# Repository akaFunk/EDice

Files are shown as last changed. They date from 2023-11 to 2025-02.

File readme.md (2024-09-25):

# EDice
The EDice is a small and fairly simple device that simulates a dice by using some LEDs, resistors and a microcontroller. The controller used is a Padauk PFS154-S16, which is an extremly cheap 8 bit microcontroller. It can be purchased from LCSC and other sources for less than 10 Euro-Cents.

The EDice is used as a simple soldering exercise. Therefore it has a combination of (relatively large) SMD and through-hole parts.

It is powered by a single CR2032 3V coin cell, which is on the back of the PCB. The holder we use is the BS-02-A1AJ010, which can also be purchased from LCSC for less than 5 Euro-Cents a pop.

Together with the PCB and a few other components, the whole cost is approximately 1€ in quantaties of about 100. This includes everything except the prommer (PCB, components, 3D case, shipping), which makes it ideal for a give-away item.

## Building
Building is pretty straight forward. A few things to note:
- Do not have a battery in the EDice while having it plugged into the prommer.
- The resistor values are quite flexible, depending on the LEDs you choose. However, the maximum source current of the microcontroller is 1.6mA on each pin. So a value of 1k or higher should be used. 1k is pretty bright though.

## BOM
We used LCSC for component sourcing. Here is our list:

- 100x microcontroller, PFS154-S16, C317613
- 100x battery holder, BS-02-A1AJ010, C5239862
- 100x button, K2-1102SP-J4SC-04, C879450
- 20x pin header,  12251140CNG0S115001,  C429959
- 700x 2.2k resistor, MFR0W8F2201A50, C58682
- 100x 100nF ceramic capacitor, CT4-0805Y104M500F1, C154503
- 700x red LED 5mm, XL-502SURD, C2895492
- 400x Screw M3x12, BB3X12, C357496

There are probably cheaper things out there, we did not look too hard into it.

## Programming

After installing the required software listed below, connect the EDice to the prommer (WITHOUT A BATTERY!) and run:

`make clean program run`

With the `run` command, the prommer will power the EDice and it should work right away.

### Programming in Linux
To program the Padauk microcontroller you need a Free-PDK prommer: https://free-pdk.github.io/

You also need to install the SDCC compiler (version 4.4.0 or higher) which you can install through your packet manager.

### Programming in Windows
Microsoft being Microsoft, it is a little more tricky to run make on Windows than it is on Linux. However, you san still do it - with a few extra steps. To run make and the programmer on Windows, you will need to:

- Install some kind of Linux shell for Windows like [Git Bash](https://gitforwindows.org/).
- Install some version of make for Windows. An easy way is using [Chocolatey](https://chocolatey.org/install) to install make by executing `choco install make` in an admin privileged command prompt.
- Install the [SDCC compiler](https://sourceforge.net/projects/sdcc/files/sdcc-win64/) (version 4.4.0 or higher). Make sure to use the provided setup.exe installer so the binary executable is added to your PATH automatically.
- Install the [Free-PDK prommer](https://github.com/free-pdk/easy-pdk-programmer-software/releases) by unpacking the .zip file, putting it somewhere with your other programs and adding the directory containing the file `easypdkprog` to your PATH manually.

After completing the installation, you can now compile and upload your code to the EDice by opening Git Bash (or another Linux Shell) in the directory containing the Makefile and running the commands listed in the section above.

## Using
Hold the button for a few seconds to roll the dice. A short press or waiting for ~20 seconds will put it in power-down mode, consuming less than 0.1µA. The battery should last for years.

## Cost
Hers is a short breakdown of the cost for 100 pcs:

- PCB at JLCPCB with shipping: 30€
- Components at LCSC with free/combined shipping (place PCB order first!): 34€
- CR2032 batteries from eBay/Amazon: 20€
- Material for 3D printing (1200g PLA): 25€

The total cost is then 99€ for 100 pcs.

This does not include the cost for the prommer, which are an additional ~25€.

## TODO
- Create a small adapter PCB for the prommer to fit into the EDice. A piece of breadboard and some pin headers will also do the trick.
- Update the 3D model and make new rendering

## License
The PCB and the images are licensed under CC-BY 4.0, the source code is under GPL v2.

For the PCB we used the KiCad symbols made by the free-pdk project: https://github.com/free-pdk/pdk-kicad-symbols/tree/master. This library is licensed under the CC-BY 4.0.

For the software the pdk-includes (GPL v2) https://github.com/free-pdk/pdk-includes and the easy-pdk-includes (GPL v2)  https://github.com/free-pdk/easy-pdk-includes are used.

## Images
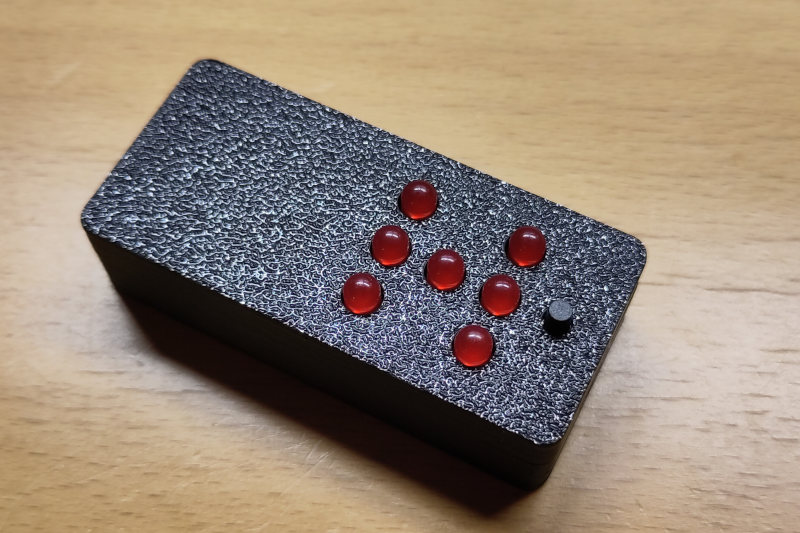
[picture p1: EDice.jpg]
EDice

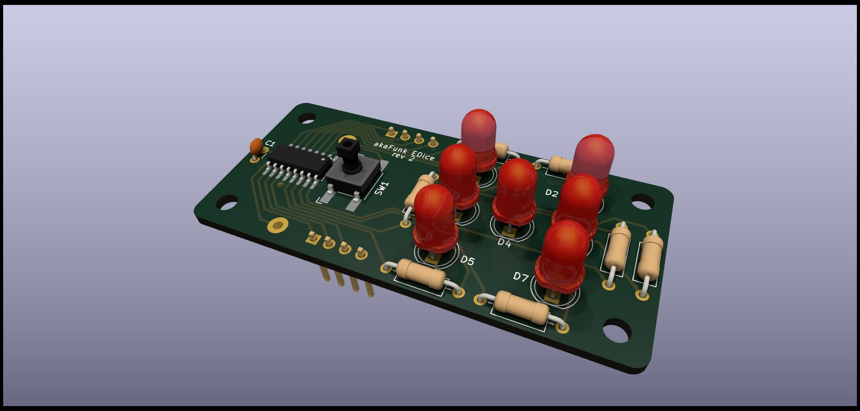
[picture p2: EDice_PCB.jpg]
EDice_PCB


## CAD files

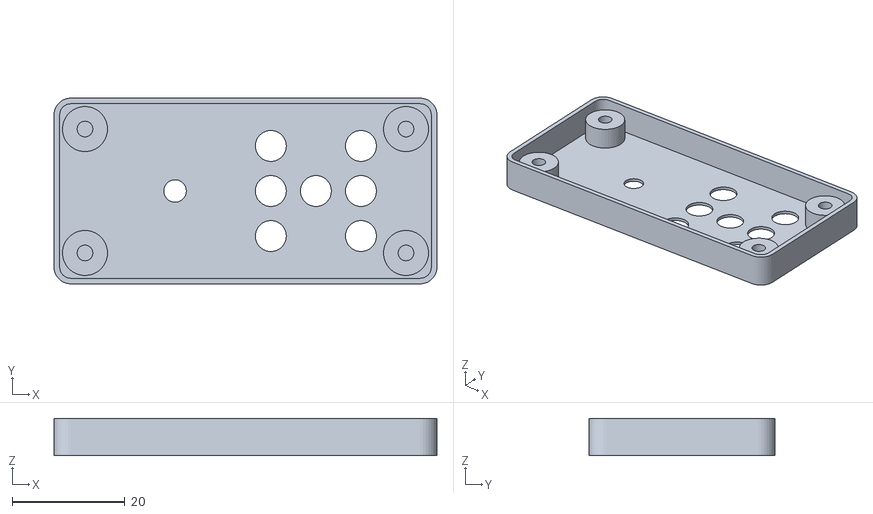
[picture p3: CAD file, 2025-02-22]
mechanical/EDiceTop.stl
68.0 x 33.0 x 6.60

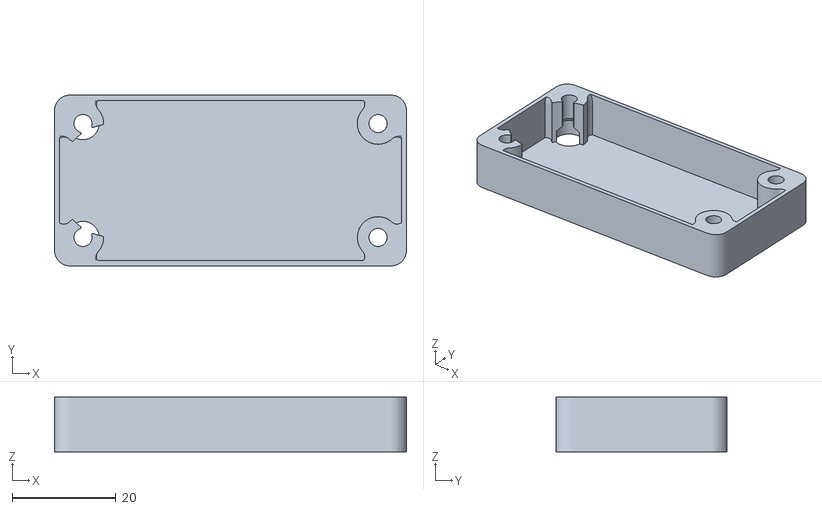
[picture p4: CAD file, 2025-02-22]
mechanical/EDiceBottom.stl
68.0 x 33.0 x 10.6

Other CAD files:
mechanical/EDiceBottom.f3d
mechanical/EDiceTop.f3d

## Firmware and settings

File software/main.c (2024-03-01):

#include "pdk/device.h"
#include "auto_sysclock.h"
#include "delay.h"

#include <stdint.h>
#include <stdlib.h>


/****************************************************
 *                                                  *
 *  board-specific and software-specific settings   *
 *                                                  *
 ****************************************************/

#define DEBUG                       0

#define SHORT_BUTTON_PRESS_MS       200
#define QUICK_CYCLE_DELAY_MS        25
#define EXTENSIVE_BUTTON_PRESS_MS   10000
#define SLOWING_CYCLE_ITERATIONS    27
#define BLINKING_ITERATIONS         6
#define HOLD_VALUE_DURATION_MS      10000

#define BOARD_REV 2

#if BOARD_REV == 1
    #define LED_PIN_D1  6
    #define LED_PIN_D2  5
    #define LED_PIN_D3  0
    #define LED_PIN_D4  3
    #define LED_PIN_D5  1
    #define LED_PIN_D6  7
    #define LED_PIN_D7  2
    #define BTN_PIN     4

#elif BOARD_REV == 2
    #define LED_PIN_D1  7
    #define LED_PIN_D2  6
    #define LED_PIN_D3  1
    #define LED_PIN_D4  3
    #define LED_PIN_D5  0
    #define LED_PIN_D6  5
    #define LED_PIN_D7  2
    #define BTN_PIN     4
#endif

/****************************************************/


#define BTN_CTRL  PBC
#define BTN_PULL  PBPH
#define BTN_DATA  PB

#define LED_CTRL PBC
#define LED_DATA PB
#define LED_MASK 0xef;

#define LED_VALUE(pin) (1<<pin)
#define BUTTON_RELEASED (BTN_DATA & (1<<BTN_PIN))
#define BUTTON_PRESSED (!BUTTON_RELEASED)

#define UINT8_TO_DIE_VALUE(val) (val % 6)
// #define UINT8_TO_DIE_VALUE(val) (3U * val / 128U)


uint8_t xorshift8(void);
void main(void);
void initializeHardware(void);
void sleep();
uint16_t quickCycle();
uint16_t slowingCycle();
uint16_t blink();
uint16_t holdValue();
void debug();
unsigned char __sdcc_external_startup(void);


uint8_t led_values[] = {
    LED_VALUE(LED_PIN_D4), 
    LED_VALUE(LED_PIN_D1) | LED_VALUE(LED_PIN_D7), 
    LED_VALUE(LED_PIN_D1) | LED_VALUE(LED_PIN_D4) | LED_VALUE(LED_PIN_D7),
    LED_VALUE(LED_PIN_D1) | LED_VALUE(LED_PIN_D2) | LED_VALUE(LED_PIN_D5) | LED_VALUE(LED_PIN_D7), 
    LED_VALUE(LED_PIN_D1) | LED_VALUE(LED_PIN_D2) | LED_VALUE(LED_PIN_D4) | LED_VALUE(LED_PIN_D5) | LED_VALUE(LED_PIN_D7), 
    LED_VALUE(LED_PIN_D1) | LED_VALUE(LED_PIN_D2) | LED_VALUE(LED_PIN_D3) | LED_VALUE(LED_PIN_D5) | LED_VALUE(LED_PIN_D6) | LED_VALUE(LED_PIN_D7)
};


uint8_t x8 = 1;

uint8_t xorshift8() {
    
    uint8_t last_x8 = UINT8_TO_DIE_VALUE(x8);

    while (UINT8_TO_DIE_VALUE(x8) == last_x8) {
        x8 ^= x8 << 5;
        x8 ^= x8 >> 3;
        x8 ^= x8 << 6;
    }

    return x8;
}


void main() {

    initializeHardware();
        
    #if DEBUG != 0

        while(1)
        {
            debug();
        }

    #else

        while(1)
        {
            while (BUTTON_RELEASED) {
                sleep();
            }

            // Sleep, if short  or extensively long button press
            if (quickCycle() <= SHORT_BUTTON_PRESS_MS) {
                continue;
            }

            if (slowingCycle()) {
                continue;
            }

            if (blink()) {
                continue;
            }

            if (holdValue()) {
                continue;
            }
        }

    #endif
}


void initializeHardware() {

    LED_CTRL |= 0xef;
    BTN_CTRL &= ~(1<<BTN_PIN);
    BTN_PULL |= (1<<BTN_PIN);

    PAPH = 0xff;
    PBPH = 0xff;
}


void sleep() {

    LED_DATA = 0;
    __stopsys();
}


uint16_t quickCycle() {

    uint16_t counter = 0;

    while (BUTTON_PRESSED) {
        LED_DATA = led_values[UINT8_TO_DIE_VALUE(xorshift8())];
        counter += QUICK_CYCLE_DELAY_MS;
        _delay_ms(QUICK_CYCLE_DELAY_MS);

        // return to sleep, if button is pressed extensively long (i.e. accidentally in a bag)
        if (counter > EXTENSIVE_BUTTON_PRESS_MS) {
            sleep();
            return 0;
        }
    }

    return counter;
}


uint16_t slowingCycle() {

    for (uint16_t i = 1; i <= SLOWING_CYCLE_ITERATIONS; i++) {

        LED_DATA = led_values[UINT8_TO_DIE_VALUE(xorshift8())];

        for (uint16_t j = 0; j < i * i / 10; j++) {
            _delay_ms(2);

            // Reset to Quick Cycle, if button is pressed
            if (BUTTON_PRESSED) {
                return 1;
            }   
        }
    }

    return 0;
}


uint16_t blink() {

    for (uint16_t i = 0; i < 2 * BLINKING_ITERATIONS; i++) {
        
        LED_DATA = (i % 2) * led_values[UINT8_TO_DIE_VALUE(x8)];
        
        for (uint16_t j = 0; j < 100; j++) {
            
            _delay_ms(1);
            
            // Reset to Quick Cycle, if button is pressed
            if (BUTTON_PRESSED) {
                return 1;
            }
        }
    }

    return 0;
}


uint16_t holdValue() {

    for (uint16_t i = 0; i < HOLD_VALUE_DURATION_MS; i++) {

        LED_DATA = led_values[UINT8_TO_DIE_VALUE(x8)];
        _delay_ms(1);

        // Reset to Quick Cycle, if button is pressed
        if (BUTTON_PRESSED) {
            return 1;
        }
    }

    return 0;
}


void debug() {

    // Test die numbers in ascending order
    for (uint16_t i = 0; i < 6; i++) {
        
        LED_DATA = led_values[i];
        _delay_ms(1000);
    }


    // Test individual LEDs in ascending order (by name)
    LED_DATA = LED_VALUE(LED_PIN_D1);
    _delay_ms(1000);
    LED_DATA = LED_VALUE(LED_PIN_D2);
    _delay_ms(1000);
    LED_DATA = LED_VALUE(LED_PIN_D3);
    _delay_ms(1000);
    LED_DATA = LED_VALUE(LED_PIN_D4);
    _delay_ms(1000);
    LED_DATA = LED_VALUE(LED_PIN_D5);
    _delay_ms(1000);
    LED_DATA = LED_VALUE(LED_PIN_D6);
    _delay_ms(1000);
    LED_DATA = LED_VALUE(LED_PIN_D7);
    _delay_ms(1000);


    // Test button functionality by activating all LEDs, if button is pressed
    uint16_t counter = 0;
    while(counter < 10000) {
        LED_DATA = (0xFF ^ LED_VALUE(BTN_PIN)) * BUTTON_PRESSED;
        _delay_ms(1);
        counter++;
    }
}


unsigned char __sdcc_external_startup(void)
{
    AUTO_INIT_SYSCLOCK();
    AUTO_CALIBRATE_SYSCLOCK(TARGET_VDD_MV);
    return 0;
}

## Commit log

2023-11-06 Added board
    [EDice-B_Cu.gbl, EDice-B_Mask.gbs, EDice-B_Silkscreen.gbo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]
2023-11-06 Added mechanical housing
    [EDiceBottom.f3d, EDiceBottom.stl, EDiceTop.f3d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]
2023-11-06 Fixed distance of pin-headers to a multiple of 2.54mm (0.1inch)
    [EDice-B_Cu.gbl, EDice-B_Mask.gbs, EDice-B_Silkscreen.gbo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]
2023-11-06 Added todo for pin change, added license info for images
2024-01-31 Move screw holes
    [EDice.kicad_pcb]
2024-01-31 swapped button to SMD and moved parts around
    [EDice.kicad_pcb, EDice.kicad_sch]
2024-01-31 aligned jumper pins to 1.27mm grid
    [EDice.kicad_pcb]
2024-01-31 moved battery holder label out of silk screen footprint
    [EDice.kicad_pcb]
2024-01-31 adjusted font size of BT1 label
    [EDice-B_Cu.gbl, EDice-B_Mask.gbs, EDice-B_Silkscreen.gbo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]
2024-01-31 Minor changes
    [EDice-B_Cu.gbl, EDice-B_Mask.gbs, EDice-B_Silkscreen.gbo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]
2024-02-07 Fixed BOM
    [EDice.kicad_sch]
2024-02-07 Added screw to BOM
2024-02-13 Update case 3D design
    [EDiceBottom.f3d, EDiceBottom.stl, EDiceTop.f3d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]
2024-02-22 modified code for board revision 2
2024-02-24 Modified xorshift() to use a macro function for mapping uint8_t to die values
2024-02-27 Reduced short button press
    [main.c]
2024-02-27 Shortened time for dice animation
    [main.c]
2024-02-27 Added feature for automatic sleep after extensively long button press
2024-02-28 Slightly improved 3D models
    [EDiceBottom.f3d, EDiceBottom.stl, EDiceTop.f3d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]
2024-08-14 Replace 100nF capacitor with better fitting type (smaller)
2024-09-25 Adjusted case length to actual PCB length and adjusted screw holes to match new screw type
    [EDiceBottom.f3d, EDiceBottom.stl, EDiceTop.f3d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]
2024-09-25 updated readme with new partnumber for screws
2024-11-19 Widened screw bore to 6.25mm diameter for easier operation
    [EDiceBottom.f3d, EDiceBottom.stl]
2025-02-22 increased wall thickness
    [EDiceBottom.f3d, EDiceBottom.stl, EDiceTop.f3d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]
